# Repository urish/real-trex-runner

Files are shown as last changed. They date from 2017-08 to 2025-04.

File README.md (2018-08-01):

# In-Real-Life TRex Runner

(https://www.youtube.com/watch?v=2SFjMK86t9Y)

## Documentation

- [About The Project + Hardware Guide](https://medium.com/@urish/i-saw-a-dinosaur-or-how-i-built-a-real-life-version-of-chrome-t-rex-game-92175f6cad2c)
- [Software Guide](https://www.javascriptjanuary.com/blog/irl-offline-t-rex-game-powered-by-javascript)

## License

[CC-BY-SA](https://creativecommons.org/licenses/by-sa/4.0/)

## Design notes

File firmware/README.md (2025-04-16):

# T-Rex Game Firmware for Raspberry Pi Pico

## Pinout

| GPIO | Peripheral | Pin  |
| ---- | --- | ---- |
| 2 | Status LED | |
| 3 | WS2812 LED | DIN  |
| 4 | DFPlayer | RX |
| 5 | E-Paper | CS |
| 6 | E-Paper | CLK  |
| 7 | E-Paper | DIN  |
| 8 | E-Paper | DC |
| 9 | E-Paper | RST  |
| 10 | E-Paper | BUSY |
| 11 | KY-024 Sensor | DO |
| 12 | Rail Motors | nSLP |
| 13 | Rail Motors | DIR  |
| 14 | Rail Motors | STEP |
| 15 | Jump Motor | nSLP |
| 16 | Jump Motor | DIR  |
| 17 | Jump Motor | STEP |
| 18 | Button | IN |

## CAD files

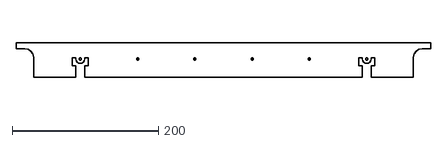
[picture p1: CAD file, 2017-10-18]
laser-cut/wall-front.dxf
567.0 x 46.8

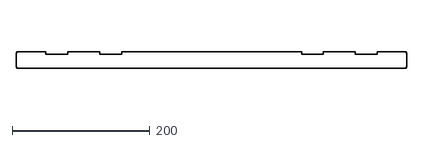
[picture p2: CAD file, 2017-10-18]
laser-cut/t-bar.dxf
567.0 x 24.0

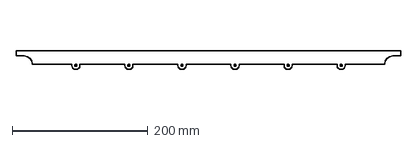
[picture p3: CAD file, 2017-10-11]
laser-cut/wall.dxf
567.0 x 28.0 mm

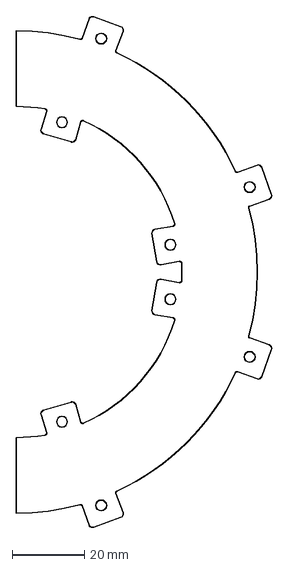
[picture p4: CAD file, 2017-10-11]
laser-cut/loop-floor.dxf
71.0 x 142.0 mm

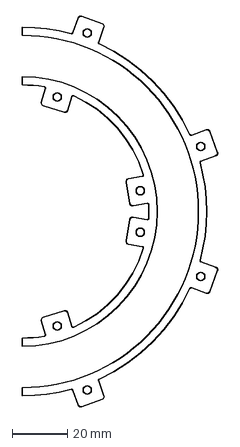
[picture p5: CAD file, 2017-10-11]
laser-cut/loop-wall.dxf
71.0 x 142.0 mm

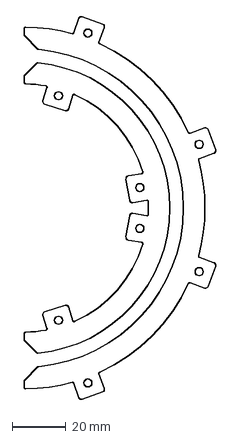
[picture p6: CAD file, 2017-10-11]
laser-cut/loop-top.dxf
71.0 x 142.0 mm

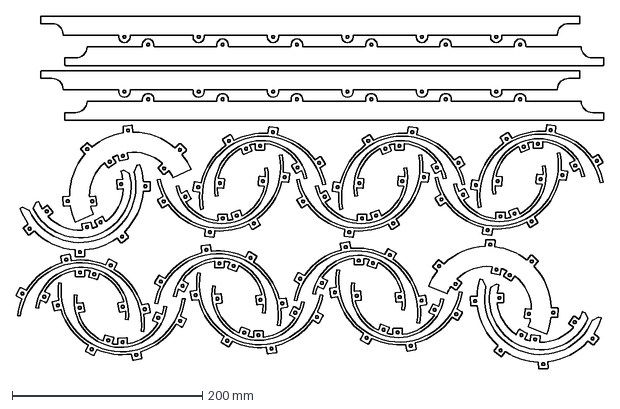
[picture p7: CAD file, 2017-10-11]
laser-cut/all-parts-plate.dxf
617.8 x 371.2 mm

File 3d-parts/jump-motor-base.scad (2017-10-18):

// Real Lonely T-Rex Game: Jump Motor Base
// Copyright (C) 2017, Uri Shaked and Ariella Eliassaf

$fn=120;

cube([20.5,25,5]);

translate([-3,0,0])
cube([3,25,15]);

translate([20.5,0,0])
cube([3,25,15]);

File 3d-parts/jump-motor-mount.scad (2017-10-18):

// Real Lonely T-Rex Game: Jump Motor Mount
// Copyright (C) 2017, Uri Shaked and Ariella Eliassaf

$fn=120;

module copy_mirror(vec=[0,1,0]) { 
    children(); 
    mirror(vec) children(); 
}

pole_radius = 8/2;
bearing_radius = 22.16/2;
bearing_distance = 36.3;
width = bearing_radius + 2;

    
translate([-25/2, -width/2,0])
cube([25, width, 6]);

difference() {
    translate([-(bearing_distance+22)/2, -width/2,0])
    cube([bearing_distance+22, width, 4]);
    
    copy_mirror([1,0,0])
    translate([-52.2/2,0,0])
    cylinder(r=3.7/2,h=5);

    translate([-bearing_distance/2,0,0])
    cylinder(r=pole_radius+1, h=5);

    translate([bearing_distance/2,0,0])
    cylinder(r=pole_radius+1, h=5);
}

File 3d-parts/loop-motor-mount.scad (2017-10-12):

// Real Lonely T-Rex Game: Loop Motor Mounter
// Copyright (C) 2017, Uri Shaked and Ariella Eliassaf

$fn=60;

side = 0; // 0 for left, 1 for right

motor_hole_height = 9;
loop_hole_inset = 3.7;

mirror([0,side,0])
union() {
    rotate([0,-90,0])
    difference() {
        union() {
            translate([0,-23,0])
            cube([2,20,13]);
            
            translate([0,-11,3])
            rotate([90,0,45])
            cube([5,4,2.5]);
        }

        translate([-0.5,-10,-0.5])
        cube([3,9,3.5]);

        translate([-0.5,-18,loop_hole_inset])
        rotate([0,90,0])
        cylinder(h=6,r=1.7);
    }
       
    rotate([90,-90,0]) {
        difference() {
            translate([4.8,3,0])
            cube([motor_hole_height+0.2,4,10]);

            translate([motor_hole_height,5,5])
            rotate([90,0,0])
            cylinder(r=1.7,h=2);

            translate([motor_hole_height,8,5])
            rotate([90,0,0])
            cylinder(r=3.1,h=3);
        }

        translate([13-8.2-5*sin(45),3,5*cos(45)])
        rotate([0,45,0])
        cube([5,4,2.5]);
        
        translate([0,3,3])
        cube([5,4,7]);       
    }
}

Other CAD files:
3d-parts/stepper-mount.scad
3d-parts/background-spacer.scad
3d-parts/bearing-holder.scad
3d-parts/bearing-shaft-spacer.scad
3d-parts/button-cover.scad
3d-parts/cactus-carrier.scad
3d-parts/jump-cap.scad
3d-parts/loop-bearing-mount.scad
3d-parts/loop-mounter.scad
3d-parts/loop.scad
3d-parts/nyloc-mount.scad
3d-parts/t-bar-mount.scad
3d-parts/trex-carrier.scad
3d-parts/wall-mount-spacer.scad
3d-parts/wall-mount.scad
3d-parts/wall-spacer.scad

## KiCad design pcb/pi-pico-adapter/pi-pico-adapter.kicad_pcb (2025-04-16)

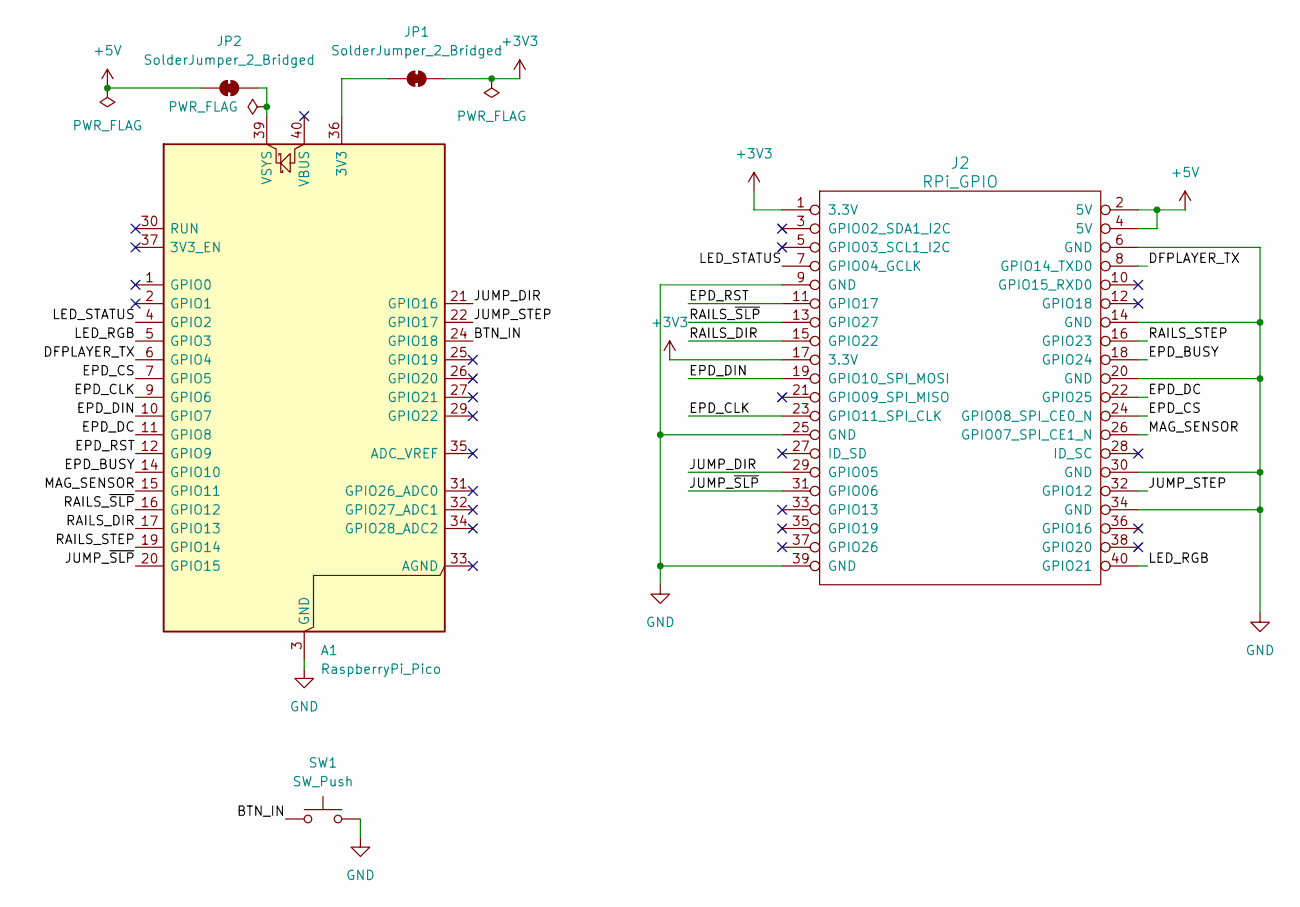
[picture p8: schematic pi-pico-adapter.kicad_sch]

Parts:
A1: RaspberryPi_Pico; RaspberryPi_Pico_Common_Unspecified
J2: RPi_GPIO; PinHeader_2x20_P2.54mm_Vertical
JP1, JP2: SolderJumper_2_Bridged; SolderJumper-2_P1.3mm_Bridged_RoundedPad1.0x1.5mm
SW1: SW_Push; PinHeader_1x02_P2.54mm_Vertical

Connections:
+3V3: J2.1 (3.3V), J2.17 (3.3V), JP1.2 (B)
+5V: J2.2 (5V), J2.4 (5V), JP2.1 (A)
/BTN_IN: A1.24 (GPIO18), SW1.1
/DFPLAYER_TX: A1.6 (GPIO4), J2.8 (GPIO14_TXD0)
/EPD_BUSY: A1.14 (GPIO10), J2.18 (GPIO24)
/EPD_CLK: A1.9 (GPIO6), J2.23 (GPIO11_SPI_CLK)
/EPD_CS: A1.7 (GPIO5), J2.24 (GPIO08_SPI_CE0_N)
/EPD_DC: A1.11 (GPIO8), J2.22 (GPIO25)
/EPD_DIN: A1.10 (GPIO7), J2.19 (GPIO10_SPI_MOSI)
/EPD_RST: A1.12 (GPIO9), J2.11 (GPIO17)
/JUMP_DIR: A1.21 (GPIO16), J2.29 (GPIO05)
/JUMP_STEP: A1.22 (GPIO17), J2.32 (GPIO12)
/JUMP_~SLP: A1.20 (GPIO15), J2.31 (GPIO06)
/LED_RGB: A1.5 (GPIO3), J2.40 (GPIO21)
/LED_STATUS: A1.4 (GPIO2), J2.7 (GPIO04_GCLK)
/MAG_SENSOR: A1.15 (GPIO11), J2.26 (GPIO07_SPI_CE1_N)
/RAILS_DIR: A1.17 (GPIO13), J2.15 (GPIO22)
/RAILS_STEP: A1.19 (GPIO14), J2.16 (GPIO23)
/RAILS_~SLP: A1.16 (GPIO12), J2.13 (GPIO27)
GND: A1.3 (GND), A1.8 (GND), A1.13 (GND), A1.18 (GND), A1.23 (GND), A1.28 (GND), A1.38 (GND), J2.6 (GND), J2.9 (GND), J2.14 (GND), J2.20 (GND), J2.25 (GND), J2.30 (GND), J2.34 (GND), J2.39 (GND), SW1.2
unnamed: A1.36 (3V3), JP1.1 (A)
unnamed: A1.39 (VSYS), JP2.2 (B)

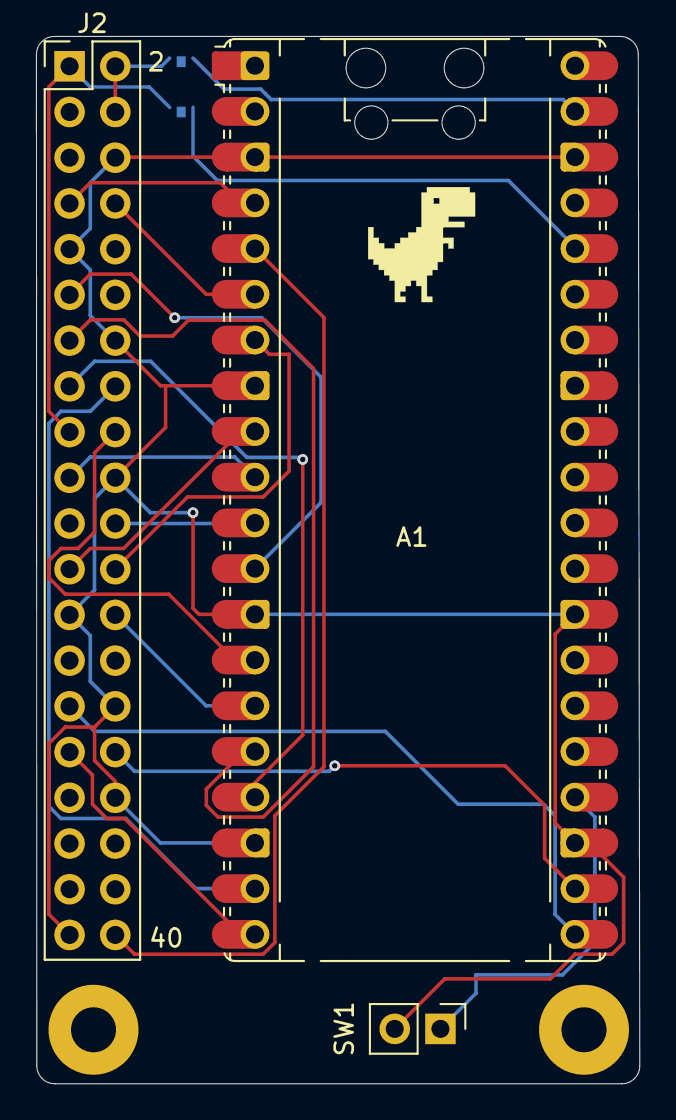
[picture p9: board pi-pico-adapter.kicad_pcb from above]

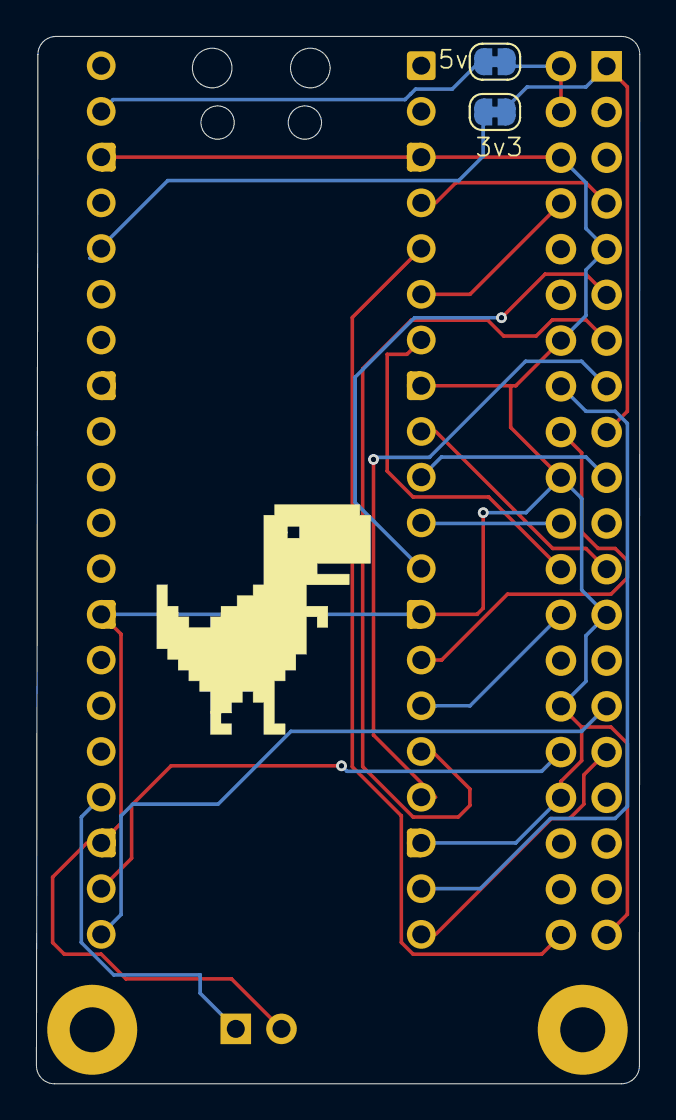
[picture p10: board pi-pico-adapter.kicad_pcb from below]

Board: 2 copper layers, 33.5 x 58.2 mm, 7 parts (3 on the bottom side), 22 nets.

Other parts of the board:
TREX1: trex
TREX2: trex-big

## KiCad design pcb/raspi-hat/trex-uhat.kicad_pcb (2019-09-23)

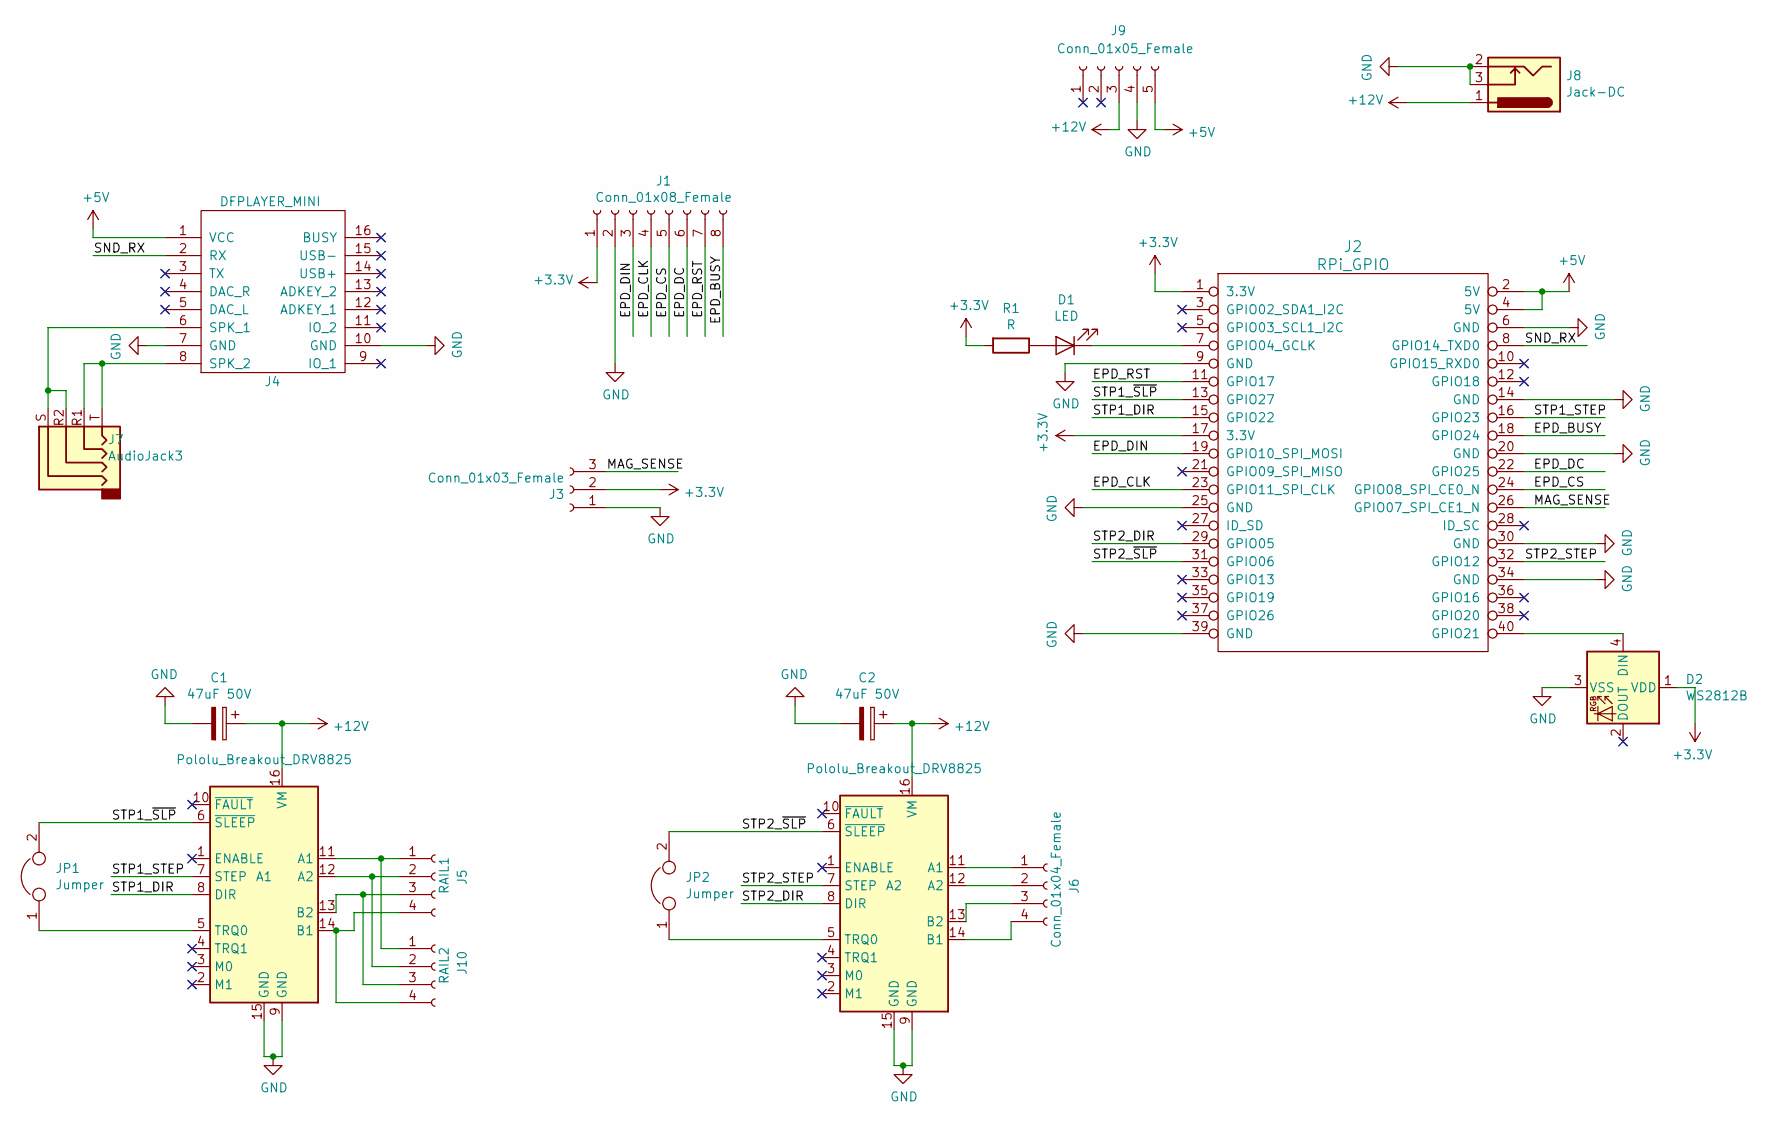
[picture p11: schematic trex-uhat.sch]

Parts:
A1, A2: Pololu_Breakout_DRV8825; Pololu_Breakout-16_15.2x20.3mm
C1, C2: 47uF 50V; CP_Radial_D6.3mm_P2.50mm
D1: LED; LED_D3.0mm
D2: WS2812B; LED_WS2812B_PLCC4_5.0x5.0mm_P3.2mm
J1: Conn_01x08_Female; PinSocket_1x08_P2.54mm_Vertical
J2: RPi_GPIO; PinSocket_2x20_P2.54mm_Vertical
J3: Conn_01x03_Female; PinSocket_1x03_P2.54mm_Vertical
J4: DFPLAYER_MINI; DFPlayer_Mini
J5: RAIL1; PinSocket_1x04_P2.54mm_Vertical
J6: Conn_01x04_Female; PinSocket_1x04_P2.54mm_Vertical
J7: AudioJack3; Jack_3.5mm_PJ320E_Horizontal
J8: Jack-DC; BarrelJack_CUI_PJ-102AH_Horizontal
J9: Conn_01x05_Female; PinSocket_1x05_P2.54mm_Vertical
J10: RAIL2; PinSocket_1x04_P2.54mm_Vertical
JP1, JP2: Jumper; SolderJumper-2_P1.3mm_Bridged_RoundedPad1.0x1.5mm
R1: R; R_1206_3216Metric

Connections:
+3V3: D2.1 (VDD), J1.1, J2.1 (3.3V), J2.17 (3.3V), J3.2, R1.2
+5V: J2.2 (5V), J2.4 (5V), J4.1 (VCC), J9.5
+12V: A1.16 (VM), A2.16 (VM), C1.1, C2.1, J8.1, J9.3
/EPD_BUSY: J1.8, J2.18 (GPIO24)
/EPD_CLK: J1.4, J2.23 (GPIO11_SPI_CLK)
/EPD_CS: J1.5, J2.24 (GPIO08_SPI_CE0_N)
/EPD_DC: J1.6, J2.22 (GPIO25)
/EPD_DIN: J1.3, J2.19 (GPIO10_SPI_MOSI)
/EPD_RST: J1.7, J2.11 (GPIO17)
/MAG_SENSE: J2.26 (GPIO07_SPI_CE1_N), J3.3
/SND_RX: J2.8 (GPIO14_TXD0), J4.2 (RX)
/STP1_DIR: A1.8 (DIR), J2.15 (GPIO22)
/STP1_STEP: A1.7 (STEP), J2.16 (GPIO23)
/STP1_~SLP: A1.6 (~SLEEP), J2.13 (GPIO27), JP1.2
/STP2_DIR: A2.8 (DIR), J2.29 (GPIO05)
/STP2_STEP: A2.7 (STEP), J2.32 (GPIO12)
/STP2_~SLP: A2.6 (~SLEEP), J2.31 (GPIO06), JP2.2
GND: A1.9 (GND), A1.15 (GND), A2.9 (GND), A2.15 (GND), C1.2, C2.2, D2.3 (VSS), J1.2, J2.6 (GND), J2.9 (GND), J2.14 (GND), J2.20 (GND), J2.25 (GND), J2.30 (GND), J2.34 (GND), J2.39 (GND), J3.1, J4.7 (GND), J4.10 (GND), J8.2, J8.3, J9.4
unnamed: A1.5 (TRQ0), JP1.1
unnamed: A1.11 (A1), J5.1, J10.1
unnamed: A1.12 (A2), J5.2, J10.2
unnamed: A1.13 (B2), J5.3, J10.3
unnamed: A1.14 (B1), J5.4, J10.4
unnamed: A2.5 (TRQ0), JP2.1
unnamed: A2.11 (A1), J6.1
unnamed: A2.12 (A2), J6.2
unnamed: A2.13 (B2), J6.3
unnamed: A2.14 (B1), J6.4
unnamed: D1.1 (K), J2.7 (GPIO04_GCLK)
unnamed: D1.2 (A), R1.1
unnamed: D2.4 (DIN), J2.40 (GPIO21)
unnamed: J4.6 (SPK_1), J7.R2, J7.S
unnamed: J4.8 (SPK_2), J7.R1, J7.T

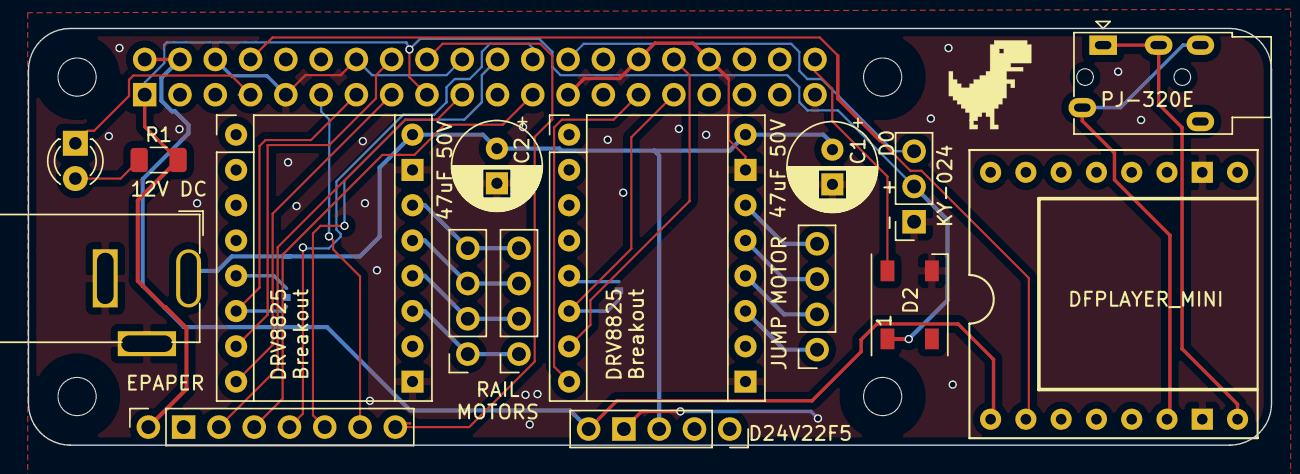
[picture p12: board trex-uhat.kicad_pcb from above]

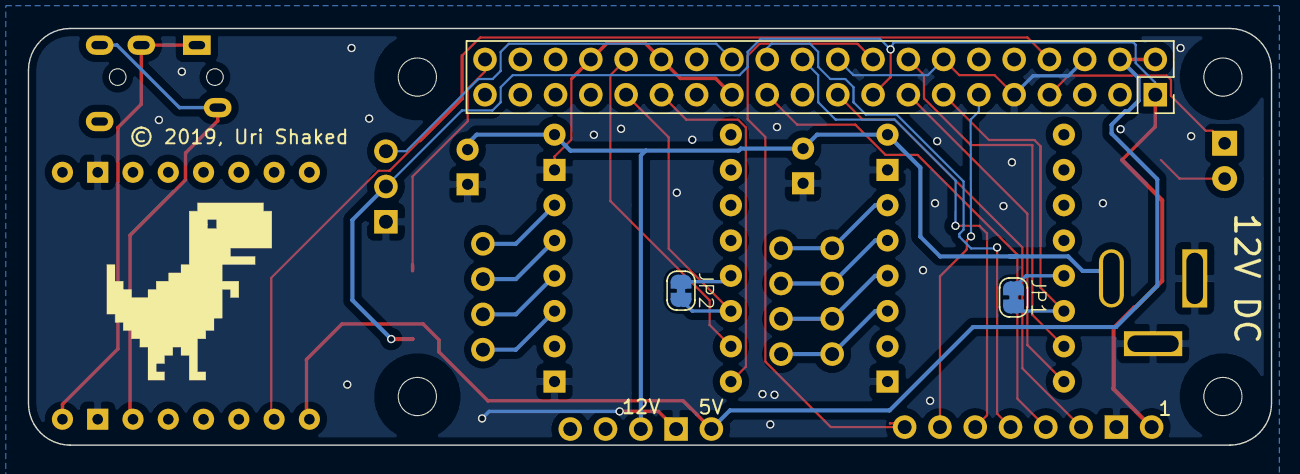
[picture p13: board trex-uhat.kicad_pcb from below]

Board: 2 copper layers, 89.5 x 30.0 mm, 21 parts (4 on the bottom side), 33 nets.

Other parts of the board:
TREX1: trex
TREX2: trex-big

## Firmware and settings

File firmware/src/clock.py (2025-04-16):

"""
Real Life Lonely T-Rex Game Firmware

Copyright (C) 2017-2024, Uri Shaked
"""

import time
from game_assets import assets
from machine import Timer

## Hardware
from machine import Pin, SPI
from display import Display

spi = SPI(0, 2000000, sck=Pin(6), mosi=Pin(7))
cs = Pin(5)
dc = Pin(8)
rst = Pin(9)
busy = Pin(10)
display = Display(spi, cs, dc, rst, busy)
###

update_timer = Timer(-1)


def zero_pad(val):
    return f"{val:02}"


def display_time(tm: time.struct_time):
    hours = tm[3]
    minutes = tm[4]
    display.clear()
    x = 40
    display.draw_string(zero_pad(hours), x, 220)
    display.draw_string(":", x, 220 - 74)
    display.draw_string(zero_pad(minutes), x, 220 - 130)
    display.update()


def clock_task(timer: Timer = None):
    tm = time.localtime()
    seconds = tm[5]
    time_to_update = 60000 - seconds * 1000 + 10
    display_time(tm)

    timer.init(mode=Timer.ONE_SHOT, period=time_to_update, callback=clock_task)


def stop():
    global update_timer
    update_timer.deinit()


def start():
    global update_timer
    stop()
    clock_task(update_timer)


if __name__ == "__main__":
    start()

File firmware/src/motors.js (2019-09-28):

const { gpio, ready } = require('./pigpio');

const MOTOR_SPEED_HZ = 600;
const MOTOR_DELAY = Math.round(1e6 / 2 / MOTOR_SPEED_HZ);

const JUMP_UP = 0;
const JUMP_DOWN = 1;

const JUMP_UP_STEPS = 500;
const JUMP_DOWN_STEPS = 480;

const rails = {
  enable: null,
  direction: null,
  step: null,
  stepHigh: null,
  stepLow: null
};

const jump = {
  enable: null,
  direction: null,
  step: null,
  stepHigh: null,
  stepLow: null
};

let railsDelayWave = null;

/**
 * Sends step pulses to the motors. We always send these pulses to the rails motors, even if
 * it is disabled (thus will the step pulses will be ignored), in order to simplify the code.
 *
 * @param {number} jumpSteps Amount of steps to move the jump motor
 */
async function sendMotorWaves(jumpSteps = null) {
  const sequence = [];
  if (jumpSteps) {
    sequence.push(
      ...[
        { loop: true },
        { waves: [rails.stepHigh, jump.stepHigh] },
        { delay: MOTOR_DELAY },
        { waves: [rails.stepLow, jump.stepLow] },
        { delay: MOTOR_DELAY },
        { repeat: jumpSteps }
      ]
    );
  }

  sequence.push(
    ...[
      { loop: true },
      { waves: [rails.stepHigh, railsDelayWave, rails.stepLow, railsDelayWave] },
      { repeat: true }
    ]
  );
  await rails.step.waveChainTx(sequence);
}

async function wait(ms) {
  return new Promise((resolve) => setTimeout(resolve, ms));
}

async function waitForJump() {
  while ((await jump.step.waveTxAt()) !== railsDelayWave) {
    await wait(1);
  }
}

async function trexUp() {
  await jump.direction.write(JUMP_UP);
  await jump.enable.write(1);
  await sendMotorWaves(JUMP_UP_STEPS);
  await waitForJump();
  await jump.enable.write(0);
}

async function trexDown() {
  await jump.direction.write(JUMP_DOWN);
  await jump.enable.write(1);
  await sendMotorWaves(JUMP_DOWN_STEPS);
  await waitForJump();
  await jump.enable.write(0);
}

async function stopRails() {
  railsRunning = false;
  await rails.enable.write(0);
}

async function startRails() {
  railsRunning = true;
  await rails.direction.write(0);
  await rails.enable.write(1);
  await sendMotorWaves();
}

async function init() {
  await ready;

  rails.enable = gpio(27);
  rails.direction = gpio(22);
  rails.step = gpio(23);
  jump.enable = gpio(6);
  jump.direction = gpio(5);
  jump.step = gpio(12);

  await rails.step.waveClear();

  for (let motor of [rails, jump]) {
    await motor.enable.modeSet('output');
    await motor.step.modeSet('output');
    await motor.direction.modeSet('output');

    // Create waveforms
    await motor.step.waveAddPulse([[1, 0, 0]]);
    motor.stepHigh = await motor.step.waveCreate();
    await motor.step.waveAddPulse([[0, 1, 0]]);
    motor.stepLow = await motor.step.waveCreate();
  }

  await jump.enable.write(0);
  await rails.enable.waveAddPulse([[0, 0, MOTOR_DELAY]]);
  railsDelayWave = await rails.enable.waveCreate();

  await stopRails();
}

module.exports = {
  init,
  startRails,
  stopRails,
  trexUp,
  trexDown
};

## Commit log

2017-08-11 add cactus PCB
    [cactus.kicad_pcb]
2017-10-02 feat: add 3D-printed parts
    [bearing-holder.scad, bearing-shaft-spacer.scad, cactus-carrier.scad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]
2017-10-04 simplify and improve loop design
    [loop.scad]
2017-10-05 feat: add display driver + unit tests
2017-10-05 feat(firmware): implement motor acceleration
2017-10-06 fix: update pin assignments
    [trex.js]
2017-10-07 update DF Player pin, default speed
2017-10-07 fix: improve jump dynamics, fix name advertising
    [trex.js]
2017-10-07 refactor: move PCB files to `pcb` directory
    [cactus.kicad_pcb, trex.kicad_pcb, trex.sch]
2017-10-07 feat: integrate display + hall sensor
    also use rollup for building the project
2017-10-08 fix: reset motor speed at the end of the game
    [trex.js]
2017-10-08 fix: improve cactus detection
    [trex.js]
2017-10-09 fix: improve bearing-holder part
    [bearing-holder.scad]
2017-10-11 feat: add laser-cut walls and loop files
    [all-parts-plate.dxf, loop-floor.dxf, loop-top.dxf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]
2017-10-12 add Loop Motor mounting part
    [loop-motor-mount.scad]
2017-10-16 feat: firmware for wireless button
2017-10-16 feat: add button cover model
    [button-cover.scad]
2017-10-16 feat: add loop mount to bearing holder
    [bearing-holder.scad]
2017-10-17 feat: wireless button, new jump mechanism
    replaced servo with a stepper for jumping
    [button.js, trex.js]
2017-10-17 feat: save graphic assets to flash
    this reduces code size and memory footprint
2017-10-17 fix: improve jump robustness, center text
    [trex.js]
2017-10-18 feat: additional 3D-printed parts
    [background-spacer.scad, jump-cap.scad, jump-motor-base.scad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]
2017-10-18 feat: add front wall, t-bar laser cut files
    [t-bar.dxf, wall-front.dxf]
2017-10-18 feat: add background laser-cut file
2017-10-21 fix(firmware): switch to soft PWM
    [trex.js]
2017-10-21 fix(firmware): throttle score updates
    also, don't try to update the display if it is busy
    this should probably fix most game glitches, especially when jumping
    [trex.js]
2017-10-22 cleanup(firmware): remove unused code from button
2017-10-22 fix: fix jump control code
    also disable the speed knob, it seems to mess up with the timings
    [trex.js]
2017-10-22 fix: improve magentic sensor code reliability
    also fix an issue with score display code
    [trex.js]
2017-10-22 fix: queue display updates
    this makes sure we always display the latest scores
    [trex.js]
2017-10-22 fix: improve cactus detection accuracy
    [trex.js]
2017-10-22 fix: ignore cacti for the first 100ms of the game
    this prevents an immediate game-over sitaution
    [trex.js]
2017-10-22 fix: reset lastCactusTime when game starts
    [trex.js]
2017-10-22 fix: level up sound did not play
    [trex.js]
2017-10-23 fix: workaround for game over issue
    [trex.js]
2017-10-23 fix: remove bluetooth control (to save firmware space)
    also try to improve responsiveness of the game
    [trex.js]
2017-10-23 fix: reliability fixes
    disable the pot knob
    set default speed to 14k
    safety-net for speedup code
    [trex.js]
2017-10-23 fix(firmware): fix game getting stuck issue
    [trex.js]
2017-10-23 fix: improve button reliability
    [button.js]
2018-06-30 fix(firmware): fix display driver to work with espruino 1v99.95
2018-06-30 fix(firmware): disable cacti sensor when not playing
    otherwise we may end up stuck in an infinite loop of cacti events if the sensor was in an unstable state when the game stopped
    [trex.js]
2018-07-01 refactor(firmware): use Object Literal Shorthand syntax
    [button.js]
2018-07-28 fix: make dino go up at the beginning of game
    [trex.js]
2018-07-28 fix(firmware): make sure display is cleared correctly when starting a game
    [trex.js]
2018-08-24 refactor(firmware): rewrite stepper control code in JS
    use nRF52 PPI hardware through NRF52LL to achieve accurate stepper motor control
2018-08-24 fix(firmware): change jump pin assignments
2019-08-21 fix(firmware): change default speed to 8k
    [trex.js]
2019-08-21 feat(firmware): implement button reconnect
2019-08-22 fix(firmware): improve jump
    also fix jump direction after hardware changes
    [trex.js]
2019-09-01 feat(pcb): Raspberry Pi ZeroW uHat PCB
    Design a uHat with all the game peripherals:
    - 2xDRV8880 Stepper Motor Driver
    - E-Paper Display connector
    - D24V22F5 5V Step-down regulator
    - KY-024 Magnetic sensor
    - 3mm LED
    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
    [trex-uhat.kicad_pcb, trex-uhat.sch]
2019-09-01 fix(pcb): mirror DRV8880 breakout
    We want the potentiometer to be up
    [trex-uhat.kicad_pcb]
2019-09-02 fix(pcb): motor connections, replace audio + power jacks
    - Change power jack from PJ-063AH to the smaller PJ-102AH
    - Change audio jack from SJ1-3533NG to PJ320E
    - Fix motor connections: connect Pi to ~SLP instead of EN
    - Improve DFPlayer Mini Footprint
    - Add silk-screen texts
    [trex-uhat.kicad_pcb, trex-uhat.sch]
2019-09-23 fix(pcb): enlarge power jack holes
    make power jack holes larger so they could fit a DC-005 jack
    [trex-uhat.kicad_pcb]
2019-09-23 feat(pcb): DRV8825 support
    [trex-uhat.kicad_pcb, trex-uhat.sch]
2019-09-23 refactor(firmware): migrate to raspberry pi
2019-09-24 refacotr(firmware): migrate display driver to pi
2019-09-24 feat(firmware): add status LED driver
2019-09-24 refactor(firmware): migrate motor code to pi
2019-09-28 feat(firmware): implement motor control for pi
    simulatenous control of jump and rail motors using pigpio
2019-09-28 feat(firmware): implement cacti sensor driver
2019-09-28 fix(firmware): firm several glitches
    - display update timings
    - cacti sensor returing too much data
    - sound sometimes not playing
    - button registers multiple disconnect callbacks
    - highscore fails when files doesn't exist
    [button.js, trex.js]
2019-09-28 fix(firmware): improve button reconnect code
    [button.js, trex.js]
2020-03-19 fix(firmware): write to display buffer line-by-line
    This aligns the code with WaveShare's example:
    https://github.com/waveshare/e-Paper/blob/8973995e53cb78bac6d1f8a66c2d398c18392f71/RaspberryPi%26JetsonNano/python/lib/waveshare_epd/epd2in9.py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
    It fixes display issues for larger buffers (e.g. full screen images)
2022-03-28 chore(deps): upgrade spi-device
2025-04-16 feat(pcb): TRex adapter PCB for Pi Pico
    [pi-pico-adapter.kicad_pcb, pi-pico-adapter.kicad_sch]
2025-04-16 feat(pcb): button input (GP18) and mounting holes
    [pi-pico-adapter.kicad_pcb, pi-pico-adapter.kicad_sch]
2025-04-16 feat(pcb): fabrication toolkit config

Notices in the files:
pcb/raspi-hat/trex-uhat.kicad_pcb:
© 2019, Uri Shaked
